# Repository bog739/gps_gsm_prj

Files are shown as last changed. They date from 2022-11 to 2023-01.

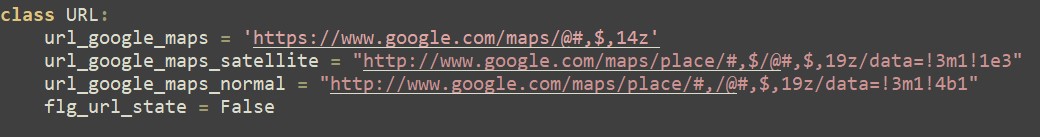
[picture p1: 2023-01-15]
kicad_schematic_pcb/Pictures/url_attributes.jpg

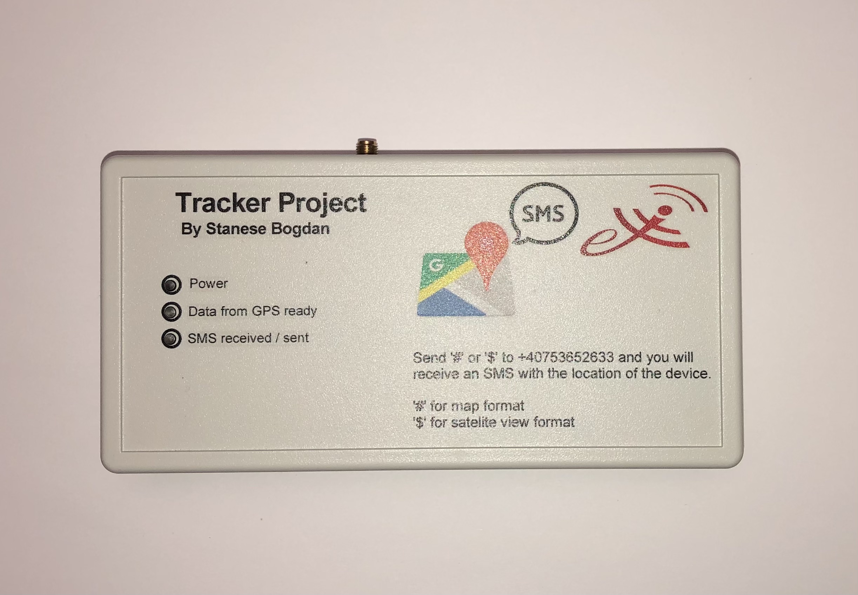
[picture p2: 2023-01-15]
kicad_schematic_pcb/Pictures/Chasis.jpg

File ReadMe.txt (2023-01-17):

-> machine module is for generic board in contrast with pyb lib

-> This project was started with gps and gsm modules
on a simple plastic board with attached cables for
TTL conversion for USB and Pycharm was used to link up
with devices.

-> In meantime the development of this project started on Pi pico, and
Thonny IDE is used afterwards, MicroPython plugin for Pycharm is not
so great. Although, Thonny IDE needs some improvement for USB communication, but for this
issue a  reset button was attached for Pi pico to re-enable the communication.

-> There is a problem for matching modules to have a perfect synchronization as close as possible,
when working on a real PCB board, taking into consideration that components are not place as close as
possible to each other's pins which traces' inductance can increase substantialy.

-> For gps module a simple solution is to use a loop to wait for gps' data to come, but
this method is not very precise because of uncertainty of synchronization between python program and
how quick gps sends its data in its specific format.

-> Basic functions read, readline, write from UART module of micropython do not work
as expected, by using uasyncio lib with StreamWriter and StreamReader classes only then characters
are stored in UART buffer and read or written as wanted. From StreamWriter class use drain function after a write func
to output buffer data or just awrite method(it uses internally drain()).

Possibilities for gsm Ctrl-Z problem:
-> It takes some time to process, send and return a status for SMS so an
immediate read doesn't report anything. A subsequent read may.
I would keep issuing read until you get something other than nothing.

-> The GA6 isn't actioning the Ctrl-Z. Issuing a write 'ABC\r' and a read
should show if it's still in its waiting for message mode.

-> For some reason the Ctrl-Z isn't being sent to the GA6.
Again, issuing a write 'ABC\r' and a read should show if it's still in its waiting for message mode.

-> Looking at what gets sent out with a Terminal Emulator
instead of the GA6 should confirm whether Ctrl-Z's are sent or not.
Being the ASCII code for "EOF - End of File' imeans it could be handled differently
to printable ASCII codes, but if that's the case would how any other GA6 user has achieved it.

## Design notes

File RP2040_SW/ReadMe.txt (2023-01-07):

-> machine module is for generic board in contrast with pyb lib

-> This project was started with gps and gsm modules
on a simple plastic board with attached cables for
TTL conversion for USB and Pycharm was used to link up
with devices.

-> Virtual environment for
python interpreter for desktop was left here if anyone
want to build it, files for pcb and scheme is yet to come !!

-> In meantime the development of this project started on Pi pico, and
Thonny IDE is used afterwards, MicroPython plugin for Pycharm is not
so great. Although, Thonny IDE needs some improvement for USB communication, but for this
issue a  reset button was attached for Pi pico to re-enable the communication.

-> There is a problem for matching modules to have a perfect synchronization as close as possible,
when working on a real PCB board, taking into consideration that components are not place as close as
possible to each other's pins which traces' inductance can increase substantialy.

-> For gps module a simple solution is to use a loop to wait for gps' data to come, but
this method is not very precise because of uncertainty of synchronization between python program and
how quick gps sends its data in its specific format.

-> Basic functions read, readline, write from UART module of micropython do not work
as expected, by using uasyncio lib with StreamWriter and StreamReader classes only then characters
are stored in UART buffer and read or written as wanted. From StreamWriter class use drain function after a write func
to output buffer data or just awrite method(it uses internally drain()).

(change a bit below)
Possibilities for gsm Ctrl-Z problem:
->It takes some time to process, send and return a status for SMS so an
immediate gsm.read() doesn't report anything. A subsequent gsm.read() might.
I would keep issuing gsm.read() until you get something other than nothing.

->The SIM800L isn't actioning the Ctrl-Z. Issuing a gsm.write('ABC\r') and a gsm.read()
should show if it's still in its waiting for message mode.

->For some reason the Ctrl-Z isn't being sent to the SIM800L.
Again, issuing a gsm.write('ABC\r') and a gsm.read() should show if it's still in its waiting for message mode.

->Looking at what gets sent out with a Terminal Emulator
instead of the SIM800L should confirm whether Ctrl-Z's are sent or not.
Being the ASCII code for "EOF - End of File' imeans it could be handled differently
to printable ASCII codes, but if that's the case would how any other SIM900L user has achieved it.

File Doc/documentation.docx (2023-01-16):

BOGDAN STĂNESE – ILIE

Tracker Project

An application

CONTENTS

1. Introduction
  a. General description
  b. A practical idea for fulfilling the need of a tracking device
  c. Aspects of improvement
2. Theoretical backround
3. Implementation
  a. Hardware
    i. Electrical schematic
    ii. PCB & ECAD
    iii. BOM
    iv. Chasis
  b. Software
    i. Programming language & IDE
    ii. Interpreter
    iii. Program
4. Conclusions
5. Bibliography
  a. Source code - Interpreter
  b. Documentation
  c. Examples on “in action” aproaches

Introduction

General description

Tracker device practically has a GPS module which keeps track of location by connecting itself to satellites around the globe and it returns data in a format similar to a vector, each field being separated by comma, and a GSM module, it receives the parsed data from GPS and by a simple algorithm of decisions, it selects each user who would try to access the device by sending a certain SMS to GSM module, the user can get approximately where the device is.

A practical idea

In some situations everyone wants to know where an important object is, for example, their phone, keys, wallet, laptop, bike, tablet, satchel, bag, purse, car, motorbike. This approach tries to fit in, but not for such small objects, like keys. It can be used inside cars or bags.

Aspects of improvement

The device size can be reduced to be used with many other gadgets. GSP and GSM modules are on separate, but much smaller, PCBs, an idea would have been to have each IC on the main board to decrease total size of device. Power supply part had not been implemented on PCB before the overall project to be done, which later would have come in handy to have all things in one place, and from this drawback, tracker device needs an external supply to power it through USB-B. Program efficiency can be increased by adding layers of error checking.

Theoretical backround

The project came with idea to have basically a working program which would have combined GPS module with a simple OLED display by using a development board. With the help of such boards we can create robust programs for prototyping, controlling and automating machine insides factories. Later on, all in one place circuits from a development board can bring up powerfull features, for example HDMI, audio codec, MIPI interfaces. This lead to the idea of having a personal and trackable device which brought in discussion the GSM module. It integrates with GSP seamlessly through a microcontroller from Raspberry Py, RP2040 which offers multi-threading features, offering a big bonus for the overall program.

Implementation

Hardware

Electrical Schematic

Power supply

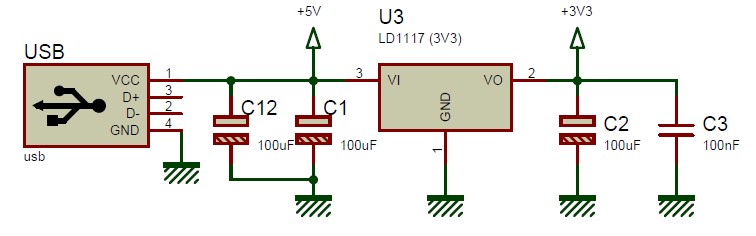
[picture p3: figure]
O imagine care conține text, ceas Descriere generată automat

An LDO voltage regulator is used to decrease the voltage from 5V to 3V3 because of GPS module. LD1117 has through-hole pins to make it easier for soldering. Decoupling capacitors help in reducing ΔVripple.

LEDs

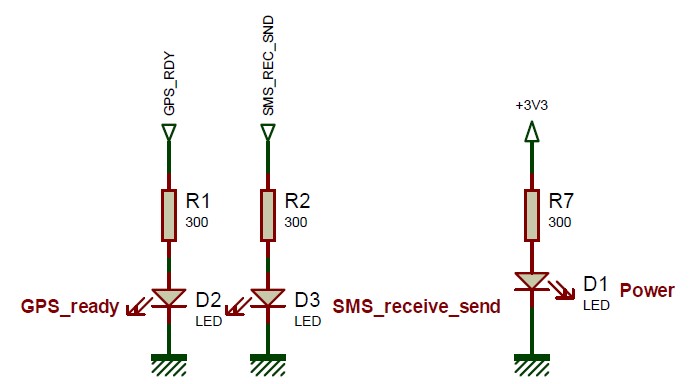
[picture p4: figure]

Leds were used to check on runtime of program what it does more precisely. RP2040 generates sufficient current to drive LEDs.

Pi Pico board

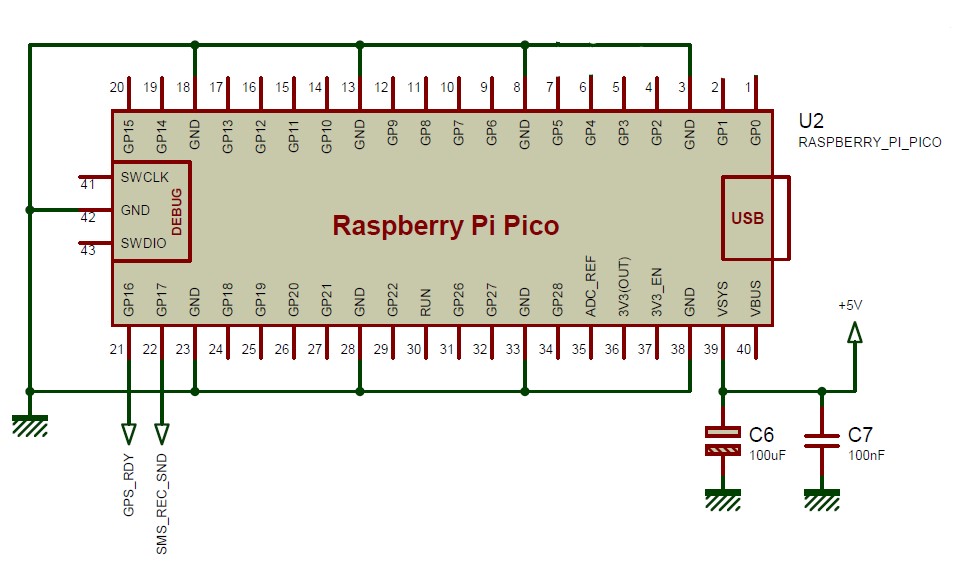
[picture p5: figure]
O imagine care conține text, dispozitiv Descriere generată automat

Decoupling capacitors are used for Vsys pin of Pi Pico board to maintain ΔVripple as low as possible. The board has a switching regulator to obtain 3V3 from 5V to supply RP2040 microcontroller.

GPS module

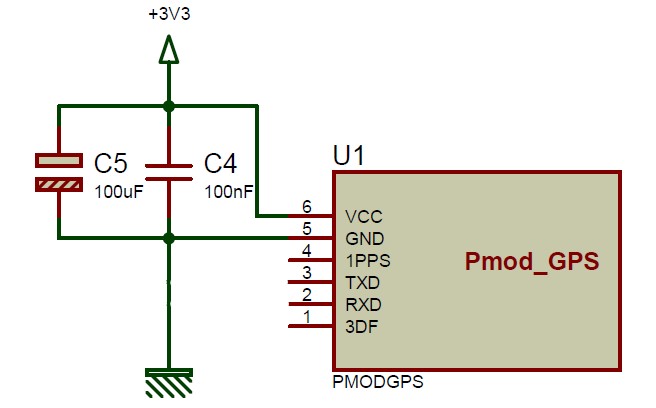
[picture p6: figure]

GPS IC is mounted on a separate PCB and its functionalities can be accessed through an external header placed on its PCB.

GSM module

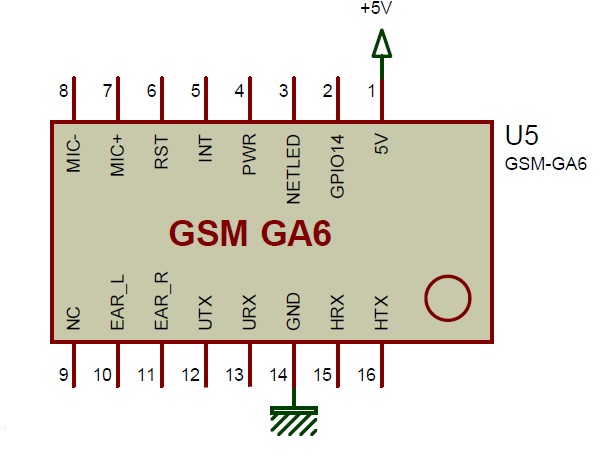
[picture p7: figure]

GSM IC as GPS IC is on its own board, it is powerd up by a switching regulator. It responses at AT commands

PCB & ECAD

In project development KiCad 6.0 and Proteus tools were used, but Proteus being a more powerful ECAD tool the final PCB design is implemented on the physical board.

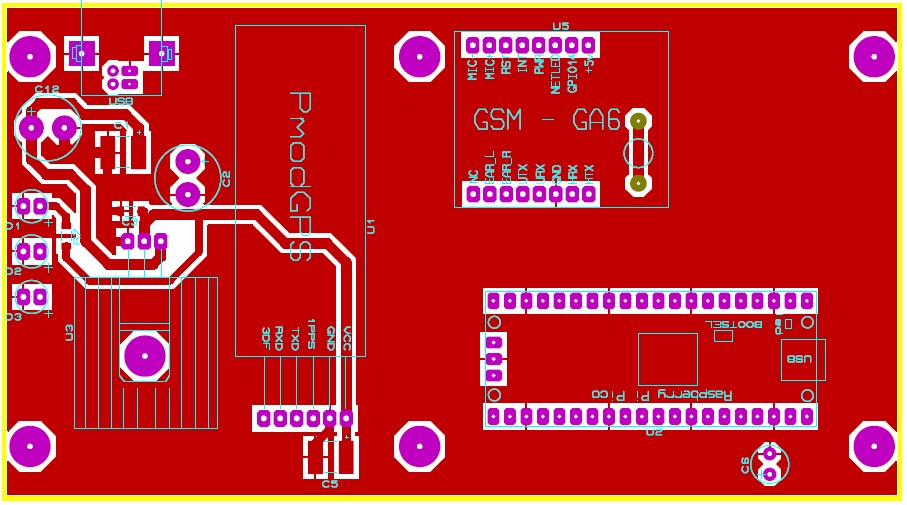
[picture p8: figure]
O imagine care conține text, circuit, electronice Descriere generată automat

Top part of PCB has almost all components, but there are on bottom part as well to route easily traces. D1 is the power LED, it take 3V3 from output of regulator to indicate the board is powerd up. Vcc of GPS module is routed directly on top to output of regulator. The USB Vcc pin is routed on bottom of PCB, regulator takes 5V from ‘+’ pin of C12, electrolytic capacitor. Under GSM module two Vias connect Vcc of USB to power up Pi Pico board at VSYS pin.

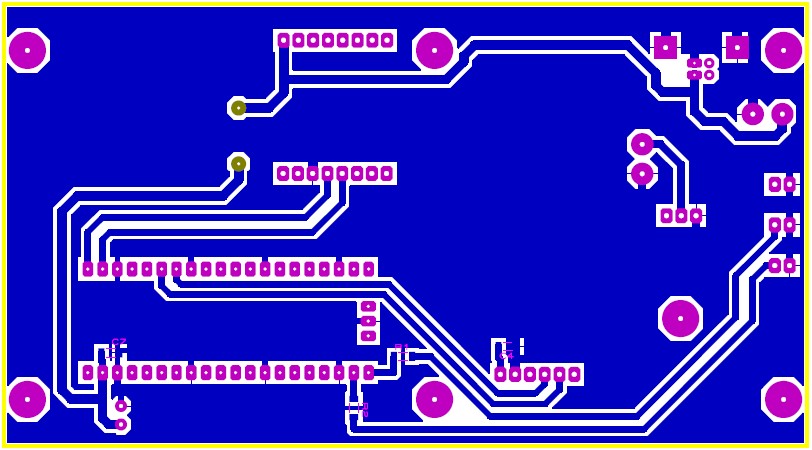
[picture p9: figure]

Bottom part of PCB has traces routed for D2 and D3 to GPIO 16, GPIO17 respectively. GPS module’s Tx and Rx are routed to GPIO5 and GPIO4, GSM module’s Tx and Rx are routed to GPIO1 and GPIO0, these are for the default UART from RP2040. The actual ground planes are created with solder masks for the GND pins.

BOM

Component Count: | 19
Ref | Qnty | Value | Cmp name
U2 | 1 | SC0915 | SC0915
C3, C4, C7 | 3 | 100nF | Tantalum type-D
C12, C1, C2, C6, C5 | 5 | 100uF | Tantalum type-D
D1 | 1 | LED_power | LED
D2 | 1 | LED_gps | LED
D3 | 1 | LED_gsm | LED
USB | 1 | USB_B | USB_B
R1 | 1 | 300Ω | 1206
R2, R3 | 2 | 300Ω | 1206
U3 | 1 | LD1117_TO-220 | LD1117_TO-220
U2 | 1 | Pmod_GPS | Pmod_GPS
U1 | 1 | GSM_module | GSM_module

Chasis

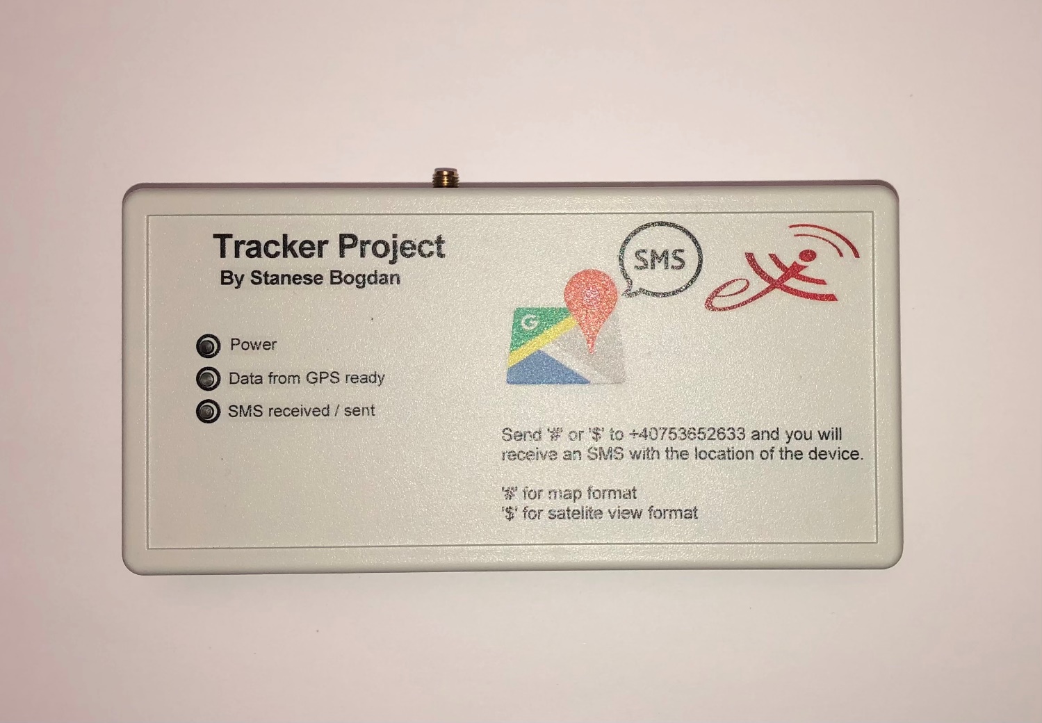
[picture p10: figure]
O imagine care conține text Descriere generată automat

Software

Programming language & IDE

Python is used for the whole program, files with source code are placed on an external flash memory from Pi Pico board and inside the RP2040 microcontroller runs MicroPython interpreter. It is placed by pressing the bootloader button from board before connecting it to an laptop through USB port and realeasing it afterwards. RP2040 will be seen as a Mass Storage Device in which by simply ‘Drag & Drop’, the interpreter can be inserted. PyCharm IDE has MicroPython Plugin, but it does not work perfectly. Thonny IDE was developed for Raspberry Py microcontrollers which works better. It is used to place source code files in the flash memory.

Interpreter

MicroPython has a good documentation and online source code on GitHub. It can be used on various microcontrollers, for example esp8266, stm 32I0, nRF52840, mimxrt, cc3200, RA4M1.

Program

All files are linked through main.py file, gps_linker.py has a class specific for GPS module with methods which parse data coming from IC, gsm_linker.py has a class intended for GSM module with methods for initialization, sending messages/receiving messages. The file reset_if_blocked.py uses WatchDog timer from RP2040 if the program has a chance to block. A class for URL formats is located in url_format.py.

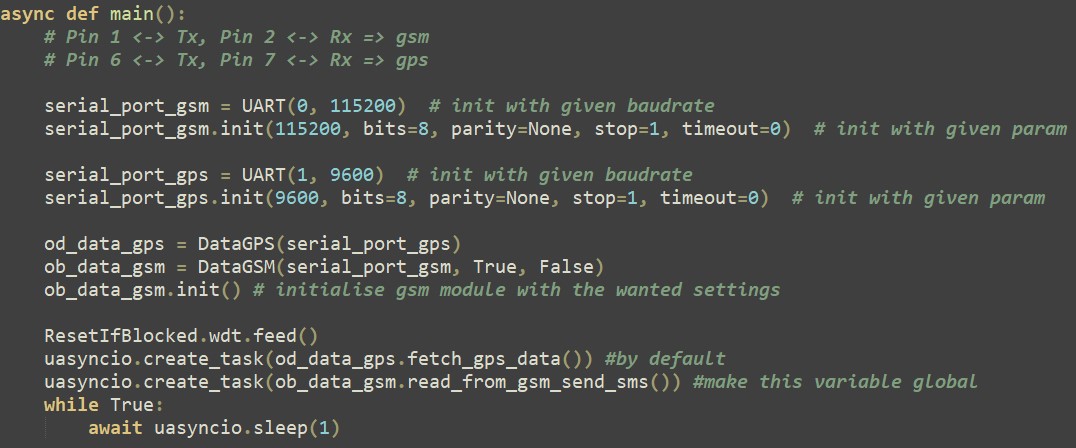
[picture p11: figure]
O imagine care conține text Descriere generată automat

In main function UART module are instantiated with specific baudrate for gsm and gps. Objects for GPS class and GSM class are then created, afterwards GSM is initialized with predefined settings. By using uasyncio module we can create tasks which run independently, await keyword is used to transform each function with async identifier into a generator which is iterated continuously by placing an endless loop at the end of main().

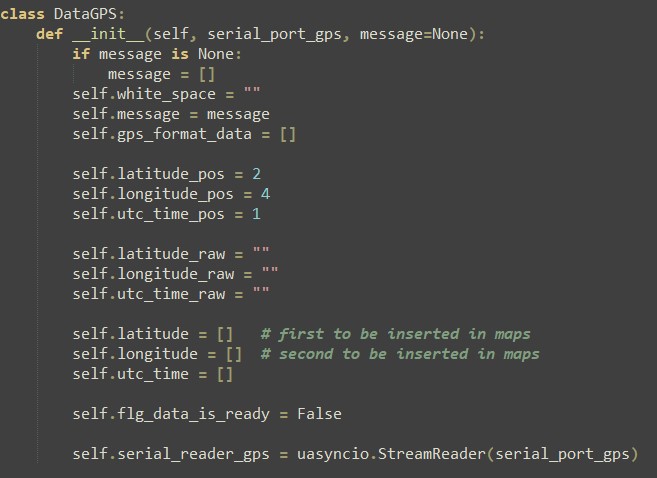
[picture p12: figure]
O imagine care conține text Descriere generată automat

In DataGPS class, contructor __init__() creates initialize attributes which are then used in internal methods. White_space is used to check for spaces when a string of data from gps is received to see if the gps has connected to satellites, if not it will put in string spaces where it did not placed real information. In message will be what GPS transmits on Tx and then parsed by parse_message method. Variables with pos extension represents where the specific items are place in string. Flg_data_is_ready will be true if data is ready to be segmented. Serial_reader_gps is an object to SteamReader class which lets us to access UART.

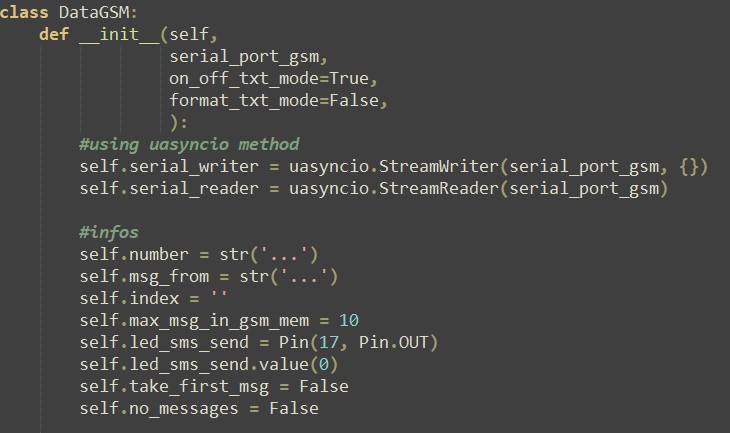
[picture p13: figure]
O imagine care conține text Descriere generată automat

GSM class has objects for reading and writing to UART via StreamWriter and StreamReader class from uasyncio module. Number will have thelephone number extracted from GSM, msg_from will get what the user sent, index keeps the index of message the GSM sets it to. Max_msg_in_gsm_mem from initialization of GSM, all messages are store in its internal memory, not on SIM card, which are maximum ten. Take_first_msg flag is used to take the index just for first message from GSM when it receives the AT command for sending on Tx all its messages. No_messages flag signals if the GSM has not a single message.

O imagine care conține text Descriere generată automat

Attributes in URL class are static because they are not in __init__() function, flg_url_state signals if the url is ready.

Wdt object connects to WatchDog timer to reset RP2040 if it blocks.

Conclusions

The project suffered various changes until it was finished, for example, because of lack of documenation for GSM module, it took some time to figure out the Tx and Rx pins work at 3V3 and 5V, and the development of program took more than expected. It is interesting that the whole program is saved by WhatchDog timer, it is not yet very clear if GSM blocks UART communication on Pi Pico board or if some signal on board disrupts the communication, when GSM receives a message or it sends one, which will lead the program to block, because source code files are not in RP2040, but in an external flash memory which RP2040 communicates through QSPI with, and the microcontroller cannot access anymore the files. SIM800L module is a better version of GSM IC.

Bibliography

Source code – Interpreter

1. MicroPython - Python for microcontrollers (https://micropython.org/download/?)
2. micropython/micropython: MicroPython - a lean and efficient Python implementation for microcontrollers and constrained systems (github.com) (https://github.com/micropython/micropython)

Documentation

1. Overview — MicroPython latest documentation (https://docs.micropython.org/en/latest/)
2. PCBDesignTutorialRevA (alternatezone.com) (http://alternatezone.com/electronics/files/PCBDesignTutorialRevA.pdf)
3. Explore SnapEDA's Symbol & Footprint Libraries | SnapEDA (https://www.snapeda.com/home/)
4. Basic AT Commands - ESP32 - — ESP-AT User Guide latest documentation (espressif.com) (https://docs.espressif.com/projects/esp-at/en/latest/esp32/AT_Command_Set/Basic_AT_Commands.html)

Examples on “in action” aproaches

1. https://github.com/peterhinch/micropython-async/blob/master/v3/docs/TUTORIAL.md#63-using-the-stream-mechanism
2. Uaysncio v3 Stream Writer Drain Bug · Issue #6621 · micropython/micropython (github.com) (https://github.com/micropython/micropython/issues/6621)
3. micropython-async/auart_hd.py at master · peterhinch/micropython-async (github.com) (https://github.com/peterhinch/micropython-async/blob/master/v3/as_demos/auart_hd.py)

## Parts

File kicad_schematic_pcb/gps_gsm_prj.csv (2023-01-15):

Date: | 1/15/2023 17:50
Tool: | Eeschema (6.0.9)
Component Count: | 16
Ref | Qnty | Value | Cmp name | Description
A1, | 1 | SC0915 | SC0915 | Pi Pico board
C1, C2, C3, C4, C5, | 5 | 10uF | T491A106K006AT | capacitors
D1, | 1 | LED_power | LED | Light emitting diode
D2, | 1 | LED_gps | LED | Light emitting diode
D3, | 1 | LED_gsm | LED | Light emitting diode
J1, | 1 | USB_B | USB_B | USB Type B connector
R1, | 1 | 300Ω | R | Resistor
R2, R3, | 2 | 10kΩ | R | Resistor
U1, | 1 | LD1117S33TR_SOT223 | LD1117S33TR_SOT223 | 800mA Fixed Low Drop Positive Voltage Regulator, Fixed Output 3.3V, SOT-223
U2, | 1 | Pmod_GPS | Pmod_GPS | gps module
U3, | 1 | GSM_module | GSM_module | gsm module

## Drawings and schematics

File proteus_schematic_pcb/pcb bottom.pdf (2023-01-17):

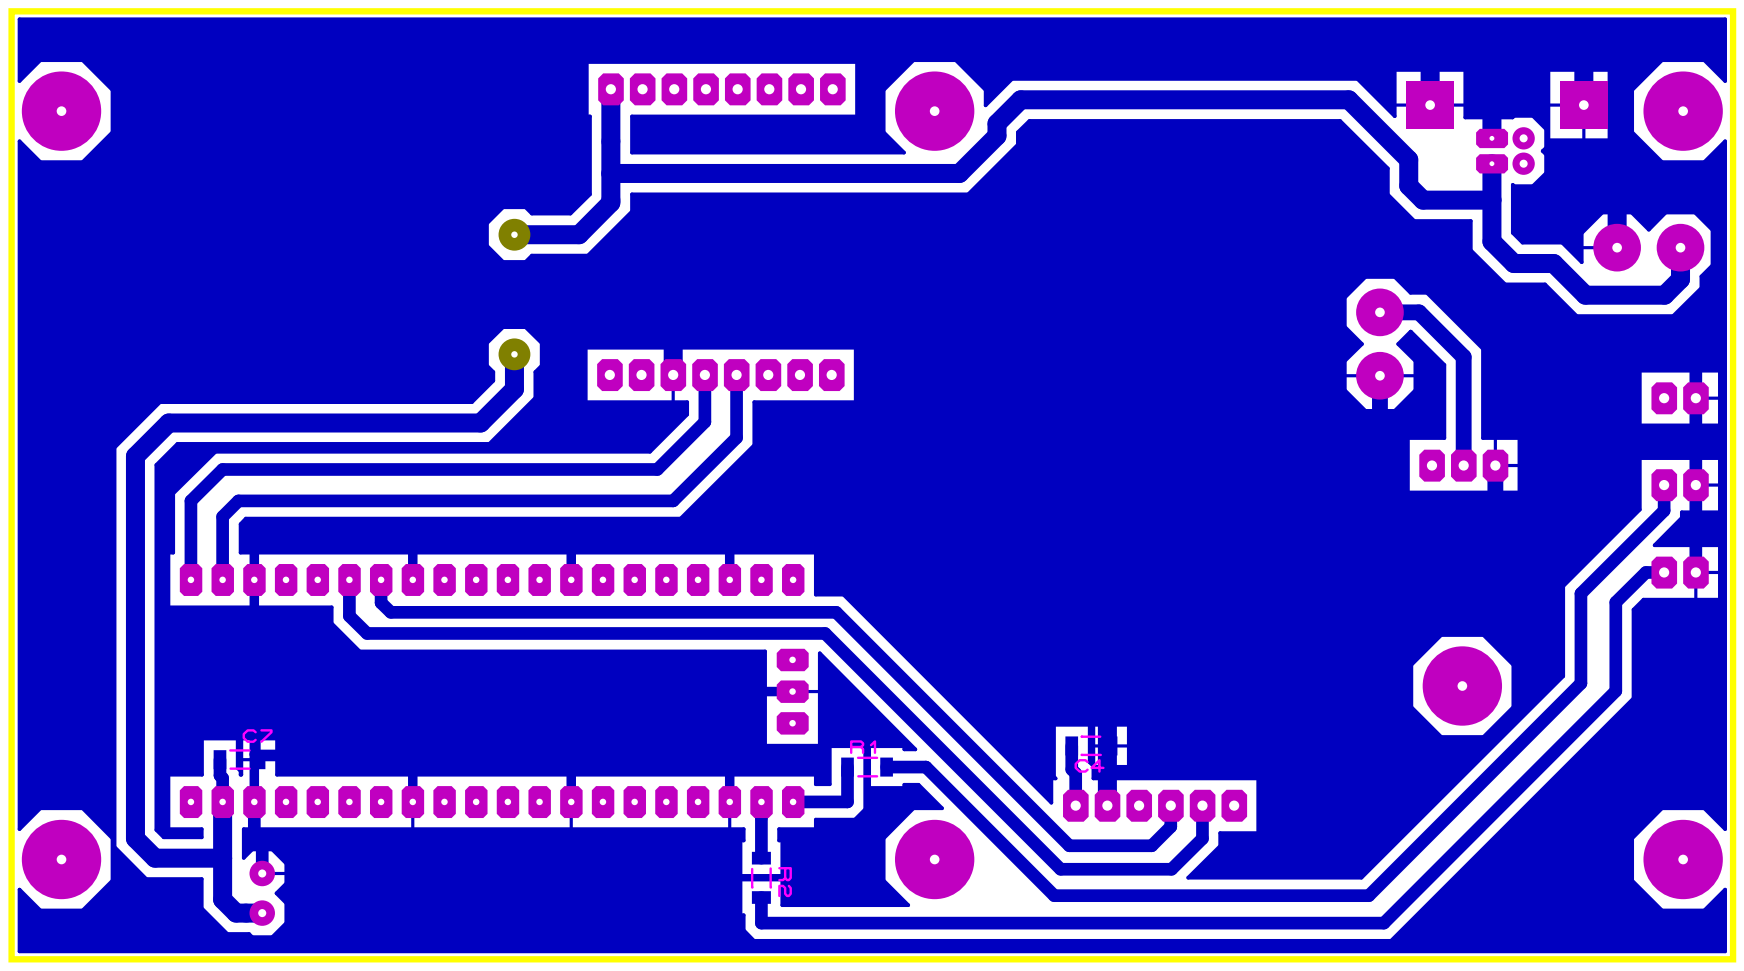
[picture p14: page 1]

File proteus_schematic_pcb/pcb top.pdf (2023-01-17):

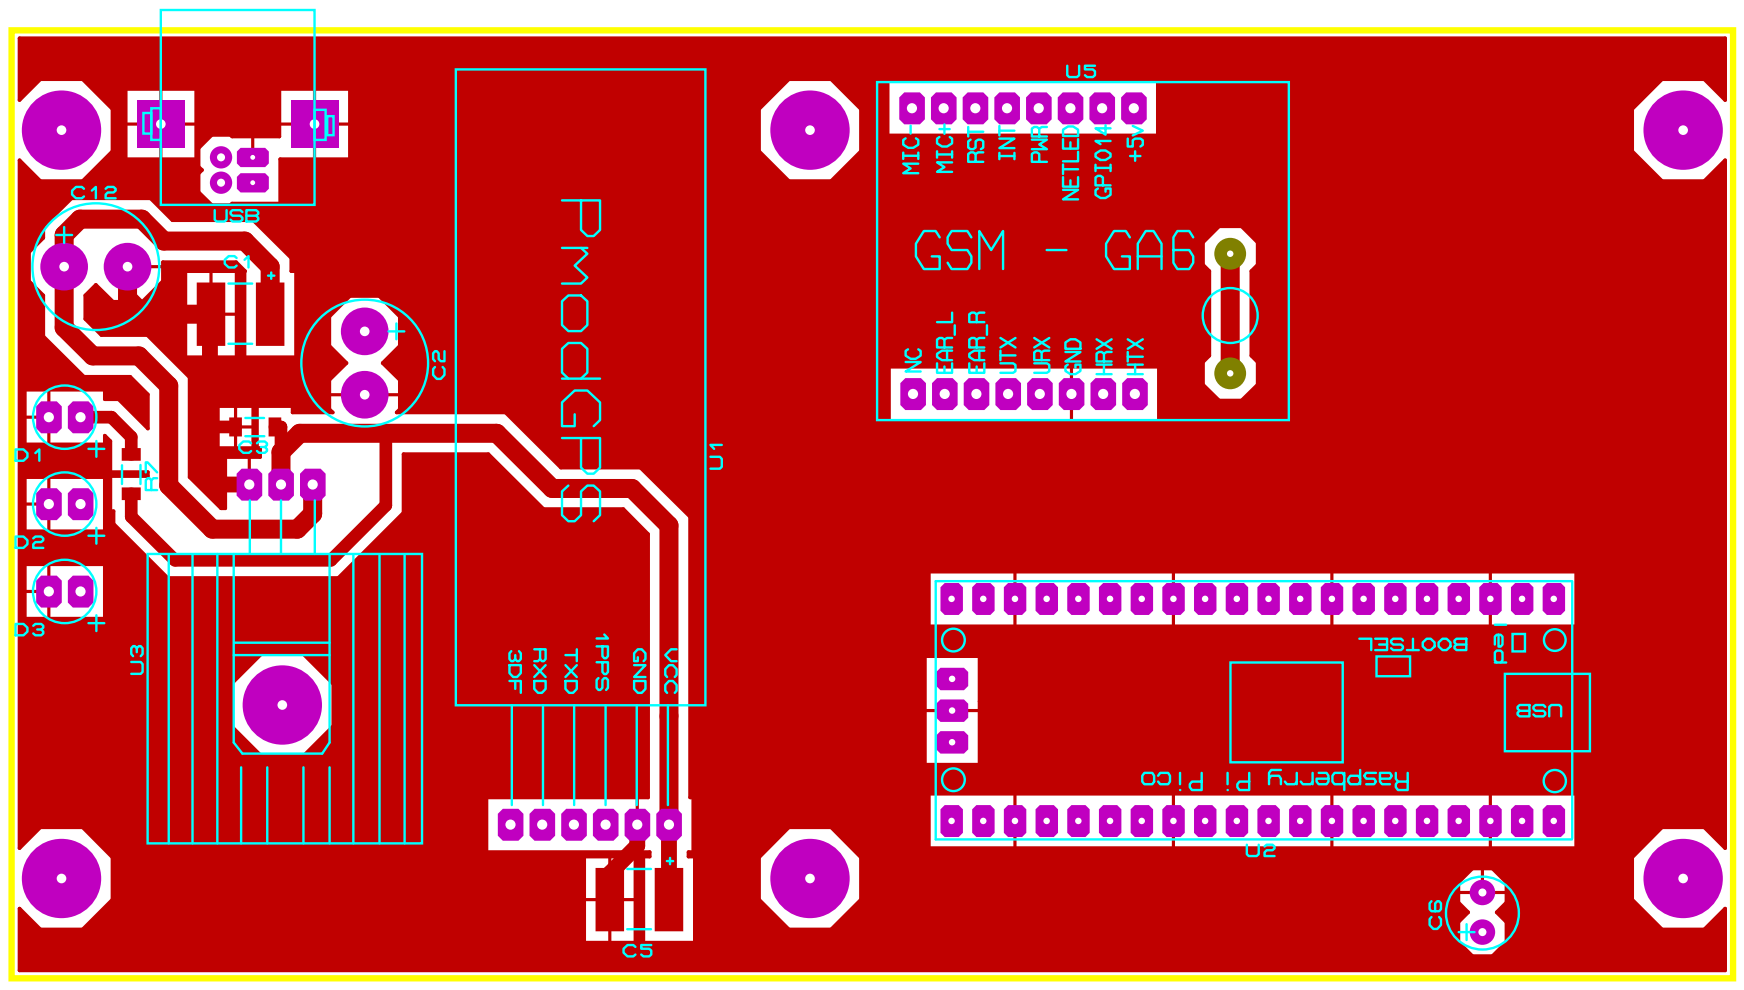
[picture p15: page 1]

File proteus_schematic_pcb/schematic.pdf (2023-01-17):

## USB

C1

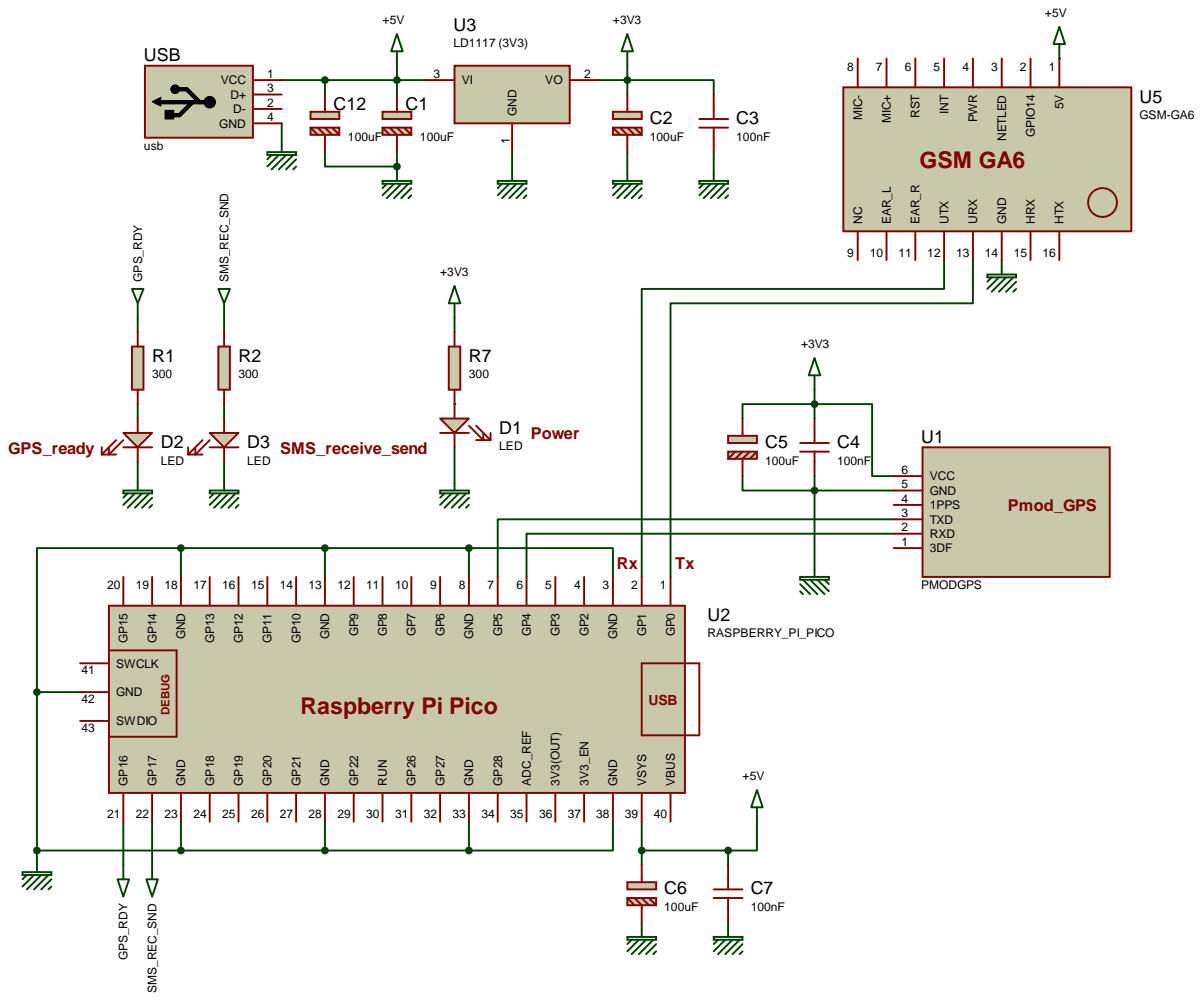
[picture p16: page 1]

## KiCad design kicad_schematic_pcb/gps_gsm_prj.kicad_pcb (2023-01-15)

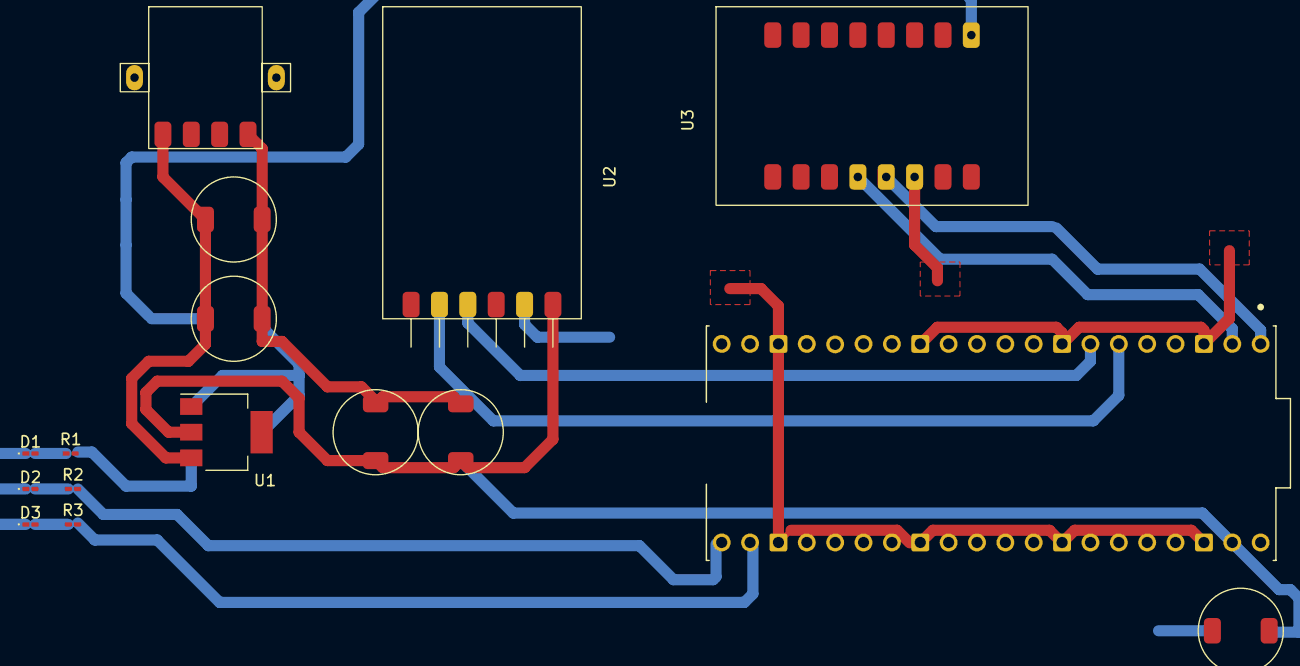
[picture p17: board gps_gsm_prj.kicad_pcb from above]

Board: 2 copper layers, 16 parts (0 on the bottom side), 8 nets.

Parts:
A1: SC0915; MODULE_SC0915
C1, C2, C3, C4, C5: 10uF; cap
D1: LED_power; LED_0201_0603Metric_Pad0.64x0.40mm_HandSolder
D2: LED_gps; LED_0201_0603Metric_Pad0.64x0.40mm_HandSolder
D3: LED_gsm; LED_0201_0603Metric_Pad0.64x0.40mm_HandSolder
J1: USB_B; USB
R1: 300Ω; R_0201_0603Metric_Pad0.64x0.40mm_HandSolder
R2, R3: 10kΩ; R_0201_0603Metric_Pad0.64x0.40mm_HandSolder
U1: LD1117S33TR_SOT223; SOT-223-3_TabPin2
U2: Pmod_GPS; gps
U3: GSM_module; gsm

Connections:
/VU1_3V3: A1.39 (VSYS), C3.1, C4.1, C5.1, U1.2 (VO), U2.6 (Vcc)
/Vin_5V: C1.1, C2.1, J1.1 (VBUS), U1.3 (VI), U3.8 (Vcc)
GND: C1.2, C2.2, C3.2, C4.2, J1.4 (GND), U1.1 (GND), U1.2 (VO)
GND1: D1.1 (K), D1.2 (A), D2.1 (K), D2.2 (A), D3.1 (K), D3.2 (A), R1.1, R1.2, R2.1, R2.2, R3.1, R3.2
GND2: C5.2, U2.5 (GND), U3.14 (GND)
unnamed: A1.1 (GP0), U3.13 (Rx)
unnamed: A1.2 (GP1), U3.12 (Tx)
unnamed: A1.3 (GND), A1.4 (GP2), A1.5 (GP3), A1.6 (GP4), A1.7 (GP5), A1.8 (GND), A1.9 (GP6), A1.10 (GP7), A1.11 (GP8), A1.12 (GP9), A1.13 (GND), A1.14 (GP10), A1.15 (GP11), A1.16 (GP12), A1.17 (GP13), A1.18 (GND), A1.19 (GP14), A1.20 (GP15), A1.23 (GND), A1.24 (GP18), A1.25 (GP19), A1.26 (GP20), A1.27 (GP21), A1.28 (GND), A1.29 (GP22), A1.30 (RUN), A1.31 (GP26), A1.32 (GP27), A1.33 (AGND), A1.34 (GP28), A1.35 (ADC_VREF), A1.36 (3V3_OUT), A1.37 (3V3_EN), A1.38 (GND), U2.2 (RX), U2.3 (TX)

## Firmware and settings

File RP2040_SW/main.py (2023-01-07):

""""
GPS 9600,   8, N, 1     -> 3.3V
GSM     115200, 8, N, 1 -> 5V power supply, but with 3.3V compatible pins
"""

from gsm_linker import DataGSM
from gps_linker import DataGPS
from reset_if_blocked import ResetIfBlocked
from machine import UART

import uasyncio

async def main():
    # Pin 1 <-> Tx, Pin 2 <-> Rx => gsm
    # Pin 6 <-> Tx, Pin 7 <-> Rx => gps

    serial_port_gsm = UART(0, 115200)  # init with given baudrate
    serial_port_gsm.init(115200, bits=8, parity=None, stop=1, timeout=0)  # init with given param
    
    serial_port_gps = UART(1, 9600)  # init with given baudrate
    serial_port_gps.init(9600, bits=8, parity=None, stop=1, timeout=0)  # init with given param
    
    od_data_gps = DataGPS(serial_port_gps)
    ob_data_gsm = DataGSM(serial_port_gsm, True, False)
    ob_data_gsm.init() # initialise gsm module with the wanted settings

    ResetIfBlocked.wdt.feed()
    uasyncio.create_task(od_data_gps.fetch_gps_data()) #by default
    uasyncio.create_task(ob_data_gsm.read_from_gsm_send_sms()) #make this variable global
    while True:
        await uasyncio.sleep(1)

if __name__ == '__main__':
    try:
        uasyncio.run(main()) # only once run the methods
    except KeyboardInterrupt:
        print('Interrupted')
    finally:
        uasyncio.new_event_loop()

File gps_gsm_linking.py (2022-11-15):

import serial
from serial.tools import list_ports
import webbrowser


class URL:
    def __init__(self):
        self.url_google_maps = 'https://www.google.com/maps/@#,$,14z'
        self.format_google_maps = 'https://www.google.com/maps/@46.7566592,23.6191744,14z'
        self.format_gm_acc = "https://www.google.com/maps/place/46%C2%B045'17.3%22N+23%C2%B034'47.9%22E/@#,$," \
                             "17z/data=!4m4!3m3!8m2!3d#!4d$"


class DataGPS:
    def __init__(self, message=None):
        if message is None:
            message = []
        self.white_space = ""
        self.message = message
        self.gps_format_data = []

        self.latitude_pos = 2
        self.longitude_pos = 4
        self.utc_time_pos = 1

        self.latitude_raw = ""
        self.longitude_raw = ""
        self.utc_time_raw = ""

        self.latitude = []   # first to be inserted in maps
        self.longitude = []  # second to be inserted in maps
        self.utc_time = []

    def add_string(self, item):
        self.message.append(item)

    def parse_message(self):
        """
        Function to parse the string of bytes coming from a GPS module,
        it starts with '$' sign and ends with <CR><LF>. Different
        info is available in this collection: latitude, longitude, utc time,
        nr of satellites
        """
        for x in range(0, len(self.message)):
            split_msg = self.message[x].split(",")  # take first one just to practice
            del split_msg[13]  # 13th element is a whitespace, from datasheet
            if self.white_space in split_msg:
                break

            self.latitude_raw = split_msg[self.latitude_pos]
            self.longitude_raw = split_msg[self.longitude_pos]
            self.utc_time_raw = split_msg[self.utc_time_pos]

            north_minutes_seconds_part = self.latitude_raw[2:]
            """ ValueError: could not convert string to float.
                Usually, this happens if the string object has
                an invalid floating value with spaces or comma
            """
            north_value_minutes_seconds_part = float(north_minutes_seconds_part) / float(60.0)
            self.latitude.append(str(float(self.latitude_raw[0:2]) + north_value_minutes_seconds_part))

            east_minutes_seconds_part = self.longitude_raw[3:]
            east_minutes_seconds_part = float(east_minutes_seconds_part) / float(60.0)
            if self.longitude_raw[0] == '0':
                self.longitude.append(str(float(self.longitude_raw[1:3]) + east_minutes_seconds_part))
            else:
                self.longitude.append(str(float(self.longitude_raw[0:3]) + east_minutes_seconds_part))

            seconds_utc_part = self.utc_time_raw[4:]
            seconds_utc_part = int(float(seconds_utc_part) % 60)
            self.utc_time.append(str(int(self.utc_time_raw[0:2]) + 2) + ':'
                                 + str(int(self.utc_time_raw[2:4]))
                                 + ':' + str(seconds_utc_part))

            self.longitude[x] = self.longitude[x][0:9]
            self.latitude[x] = self.latitude[x][0:9]
            self.gps_format_data.append("UTC time: " + self.utc_time[x] + ", Longitude: "
                                        + self.longitude[x] + ", Latitude: " + self.latitude[x])

    def display_(self):
        for x in range(0, len(self.message)):
            print(self.gps_format_data[x])


def swap(prev_val_x, prev_val_y):
    a, b = prev_val_y, prev_val_x
    return a, b


if __name__ == "__main__":
    comports_ = [list(list_ports.comports())]

    gps_module_port = comports_[0][0].device
    gsm_module_port = comports_[0][1].device

    serialPort = serial.Serial(port=gps_module_port, baudrate=9600,
                               bytesize=8, timeout=1, stopbits=serial.STOPBITS_ONE)
    serialPort.close()

    # For gsm module it is not mandatory to write smth to it,
    # from it we can use only Rx pin and to parse the existing
    # string of bytes.

    serialPort.open()
    dummyByte = serialPort.read(1)
    if dummyByte != b'$':    # use != if gps var is used above
        serialPort.close()
        gps_module_port, gsm_module_port = swap(gps_module_port, gsm_module_port)

    serialPort.close()
    serialPortGsm = serial.Serial(port=gsm_module_port, baudrate=115200, bytesize=8,
                                  timeout=1, stopbits=serial.STOPBITS_ONE)
    serialPortGps = serial.Serial(port=gps_module_port, baudrate=9600, bytesize=8,
                                  timeout=1, stopbits=serial.STOPBITS_ONE)

    messageGPS = ""
    commandATGsm = ""

    startByte = bytes(1)
    readByte = bytes(1)

    data_line_extracted = 10
    ob_data_gps = DataGPS()
    try:
        for i in range(data_line_extracted):
            startByte = serialPortGps.read(1)
            gpsDataFormatGGA = False
            messageGPS = ""

            while True:
                readByte = serialPortGps.read(1)
                if readByte == b'\n' or readByte == b'\r':
                    break
                messageGPS = messageGPS + str(readByte.decode('ascii'))

            gpsDataFormatGGA = messageGPS.startswith('GPGGA')
            if gpsDataFormatGGA:
                ob_data_gps.add_string(messageGPS)

        ob_data_gps.parse_message()
        ob_data_gps.display_()
    except KeyboardInterrupt:
        pass
    serialPortGps.close()

    url_data_gps = URL()
    url_data_gps.format_gm_acc = url_data_gps.format_gm_acc.replace("#", ob_data_gps.latitude[0])
    url_data_gps.format_gm_acc = url_data_gps.format_gm_acc.replace("$", ob_data_gps.longitude[0])
    webbrowser.open_new_tab(url_data_gps.format_gm_acc)
    """ for using only open()
        new=0 -> url open in the same browser window 
        new=1 -> a new browser window is opened
        new=2 -> a new browser tab is opened
    """

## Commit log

2022-12-01 started dev for pi pico, changes for all files may be needed
2022-12-01 a small refacto on main.py file to fit in Pi Pico
2022-12-22 started developing schematic and pcb layout in KiCad
    [gps_gsm_prj.kicad_pcb, gps_gsm_prj.kicad_sch]
2023-01-06 Problems occured with UART communication, but using uasyncio lib aprox solved the issue
    [gps_linker.py, gsm_linker.py, main.py]
2023-01-15 KiCad files for schematic and PCB - v1.0
    [gps_gsm_prj.kicad_pcb, gps_gsm_prj.kicad_sch]
2023-01-15 documentation for project
    [gps_gsm_prj.csv, gps_gsm_prj.kicad_sch]
